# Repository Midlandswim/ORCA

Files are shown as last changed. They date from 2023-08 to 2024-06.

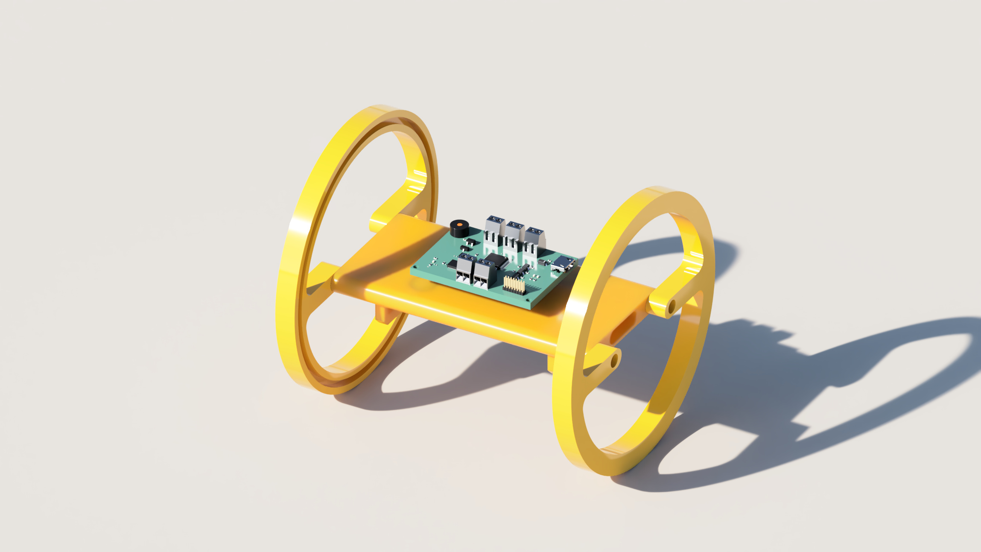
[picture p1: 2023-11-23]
Media/RandomProgressPics/ORCA_Electronics_Bay_2023-Nov-12_01.jpg

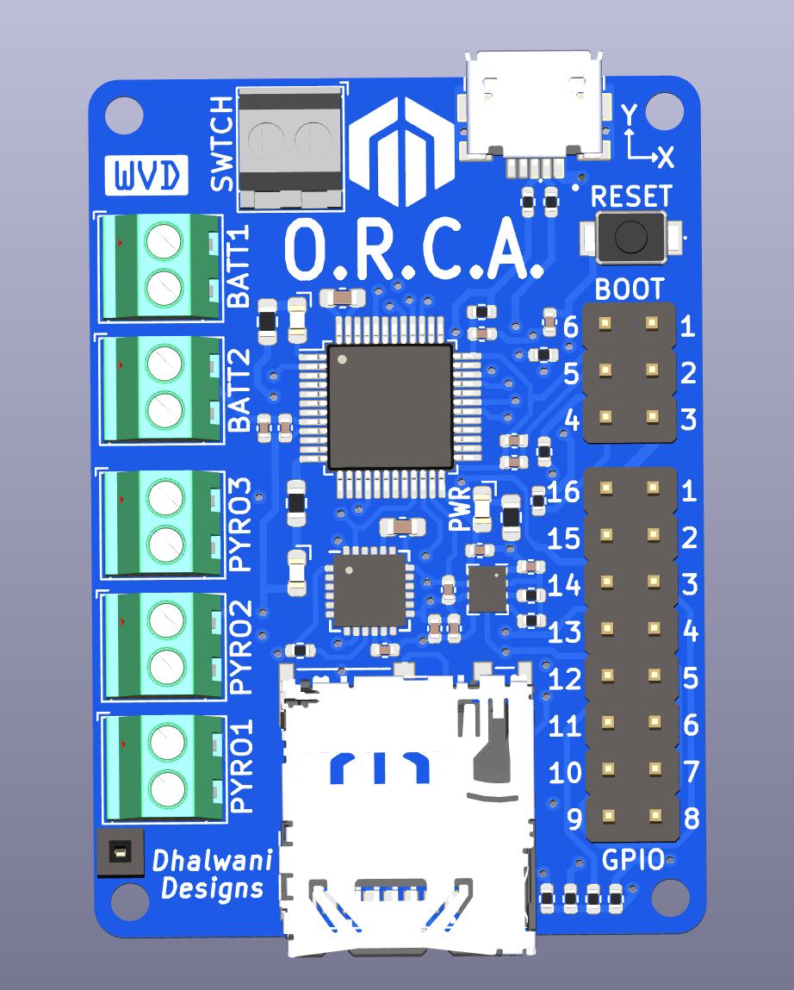
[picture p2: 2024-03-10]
Media/Version 4.0/Screenshot 2024-03-10 141300.png

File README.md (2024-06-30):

# O.R.C.A
Optimized Rocketry Computer Assembly

This is in partnership with Dhalwani Designs, which holds all rights, data, and procedures for this project and the related. <br />

Researcher: Wilson Dhalwani <br />
Aides: Mr. Michael Liva (BCA) & Mr. Joseph Barbetta (BCA) & Mr. Vladyslav Kharechko (BCA) <br />
Context: Dhalwani Designs Sanctioned Project, Senior Capstone, and Electrical Engineering Research Project <br />
Project Name: The Optimized Rocketry Computer Assembly <br />
Start Date: June 06, 2023 <br /> 

The following repository is for documenting and sharing my work in this research and capstone project and its related fields of electrical and avionics engineering. This was also made to record my process of solving the issue at hand so that others can learn and build upon my work. The O.R.C.A was inspired by work and research with various competitive rocketry teams, who came with concerns for traditional flight computers, which tended to be large, involved, and bulky, affecting performance and technical usage. This led to me going down a rabbit hole of avionics and the niche community that came with flight computer design. After spending hours in KiCAD, EAGLE, and JLCPCB Assembly Libraries, I found myself intrigued by the idea of an ultra-compact, one that was far smaller than the conventional flight computer and many times more capable. And, after many weeks of research and design, I came up with the first prototype for O.R.C.A, a board that was 60 mm by 72 mm, however, this was not good enough. Small was the name of the game, and with the discovery of 0402 SMD components, I managed to bring it down to less than 47 mm by 34 mm, small enough to fight in the palm of your hand! I would eventually bring this work over, as part of my Senior Engineering Capstone (yes, I am ahead of schedule), to hopefully share my work in avionics so that others could be inspired by what I did, and collaborate towards even smaller boards. The evolution of Printed Circuit Board design is at its peak, and the innovation in the electronics industry is mesmerizing, allowing for some cool creations and hopefully even more compact and powerful designs in the future. With that being said, optimized is used loosely, as I am sure in a month or so, we will have components even smaller than 0201 generally available, especially with the recent advances in Flex PCBs. I completely designed the entire system, top-down, using KiCAD, snapEDA for parts libraries, and JLCPCB for SMD component libraries. The amazing thing about this board, despite its size and power, is its capability and the ability to be applied to many scenarios and uses. With the great populace of onboard sensors, abundant and expandable memory, and the amazing MCU, this board can be programmed for rockets, drones, and more. Currently, time is being spent on updating and improving firmware, and work is currently being done on a new and improved version 4.0, so be on the lookout for that in the coming months! This project has no end date as an innovation never ends, rather, continues until the idea is forgotten, and my hope is that this work can be the basis for future engineers who, too, find great excitement in innovation and design. <br />

Should you have any questions, comments, or just wish to reach out, email me at wilson.dhalwani@gmail.com !

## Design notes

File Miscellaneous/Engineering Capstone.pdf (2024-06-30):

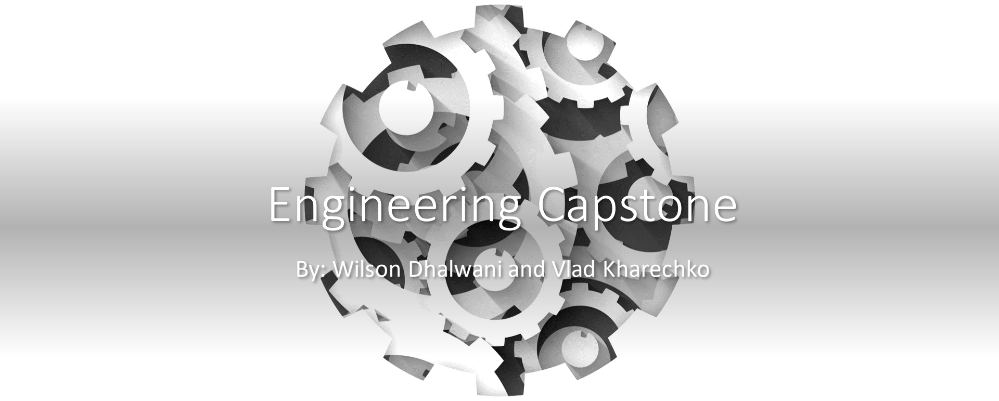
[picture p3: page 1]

# Engineering Capstone

## By: Wilson Dhalwani and Vlad Kharechko

# Idea

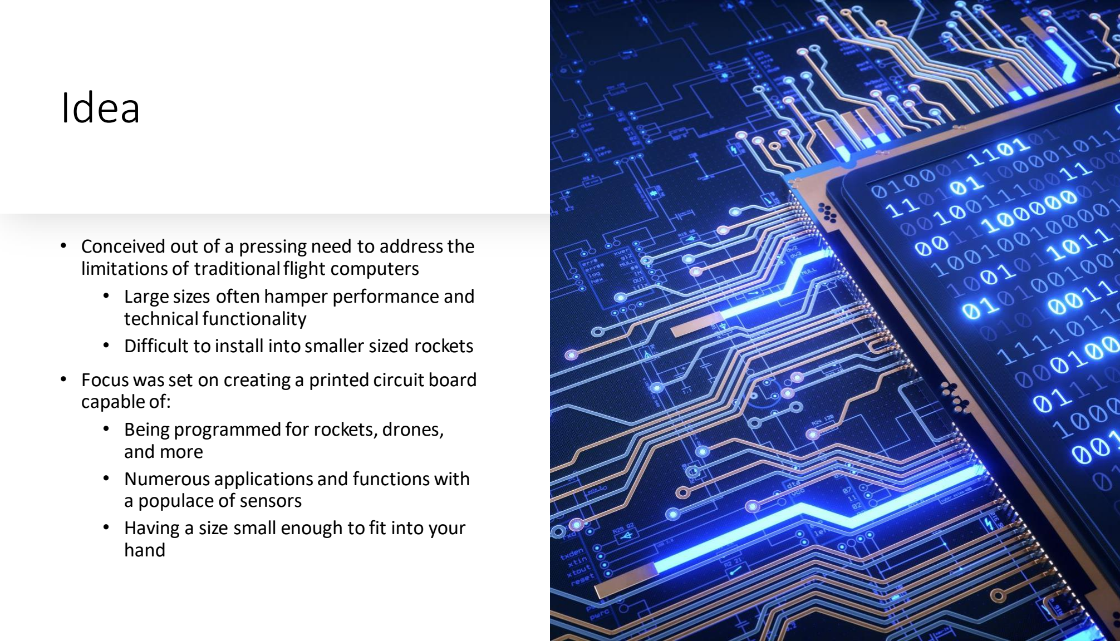
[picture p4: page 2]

- Conceived out of a pressing need to address the limitations of traditional flight computers
- Large sizes often hamper performance and technical functionality
- Difficult to install into smaller sized rockets
- Focus was set on creating a printed circuit board capable of:
- Being programmed for rockets, drones, and more
- Numerous applications and functions with a populace of sensors
- Having a size small enough to fit into your hand

# Solution - O.R.C.A

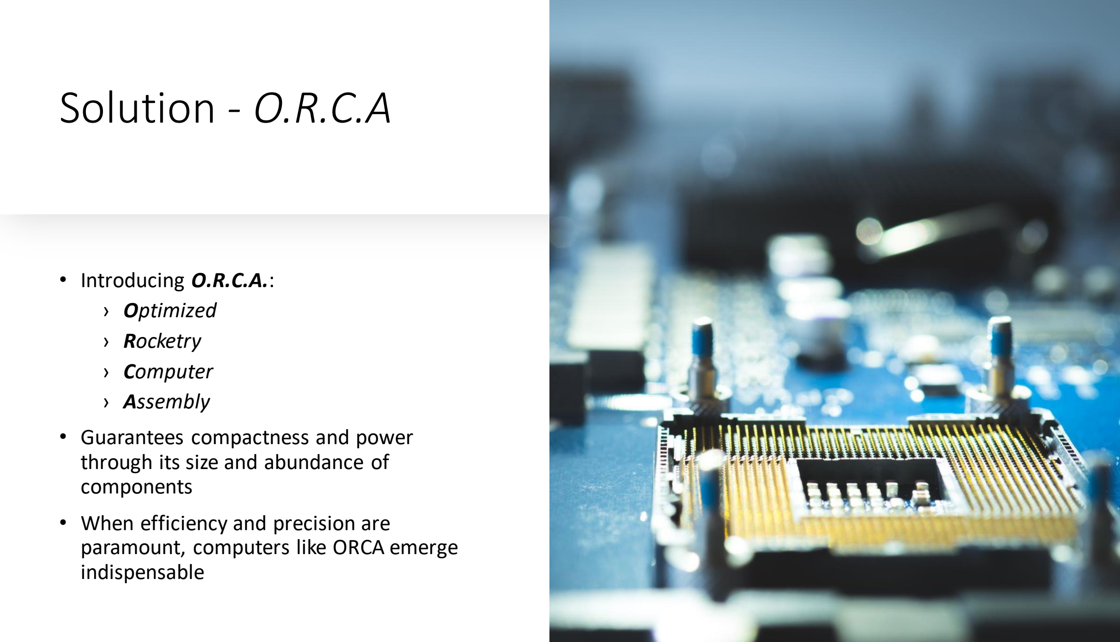
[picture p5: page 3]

### - Introducing O.R.C.A.: › Optimized › Rocketry › Computer › Assembly - Guarantees compactness and power through its size and abundance of components

### - When efficiency and precision are paramount, computers like ORCA emerge indispensable

# Bill of Materials

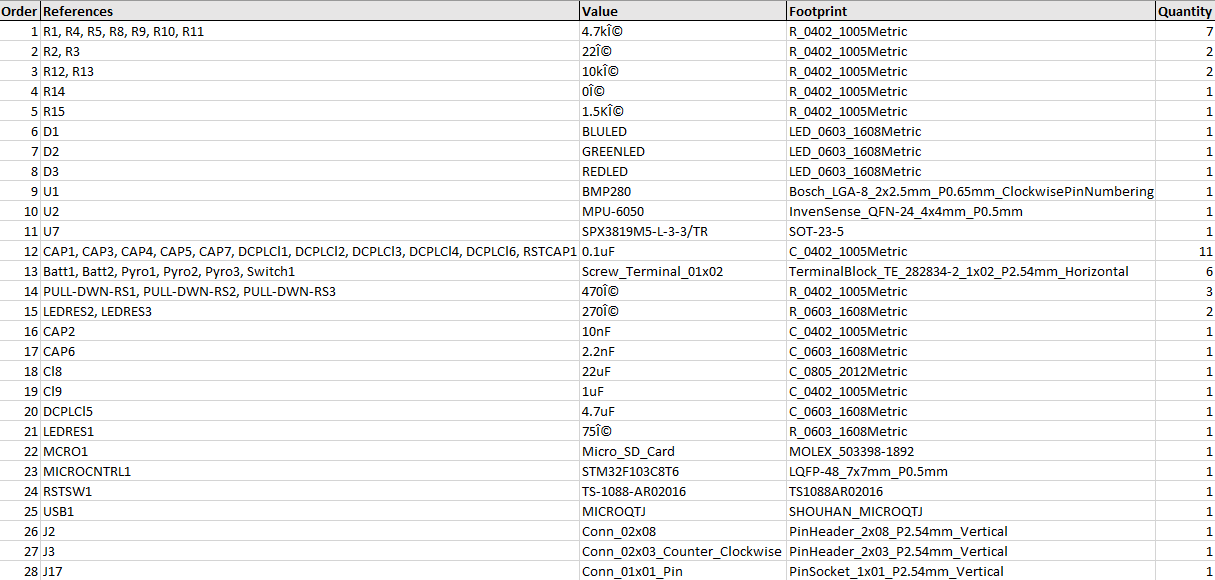
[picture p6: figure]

# Visuals

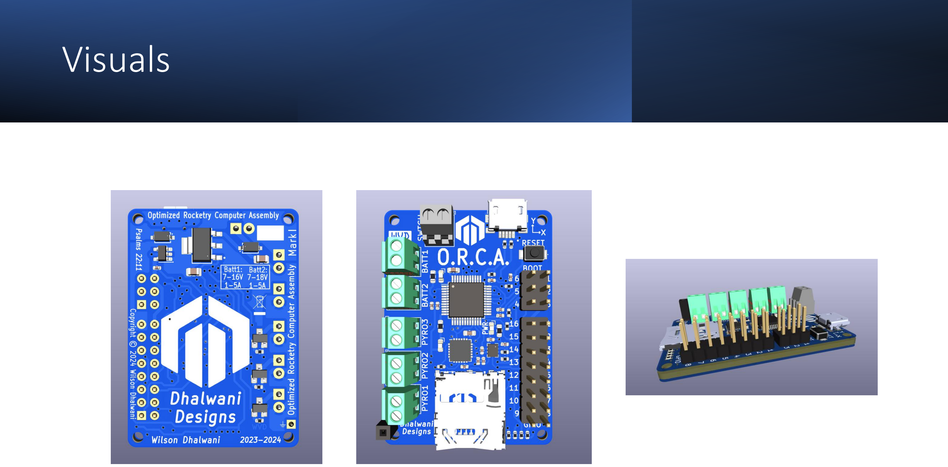
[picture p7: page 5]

# Tools Used

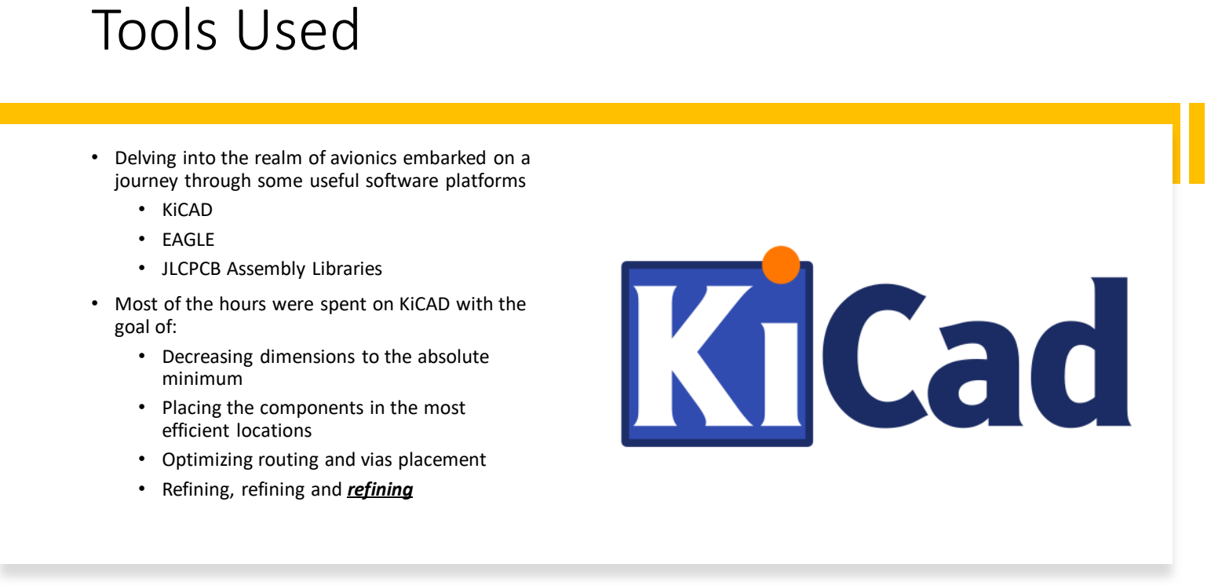
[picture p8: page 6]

- Delving into the realm of avionics embarked on a journey through some useful software platforms
- KiCAD
- EAGLE
- JLCPCB Assembly Libraries
- Most of the hours were spent on KiCAD with the goal of:
- Decreasing dimensions to the absolute minimum
- Placing the components in the most efficient locations
- Optimizing routing and vias placement
- Refining, refining and refining

# Sponsorship

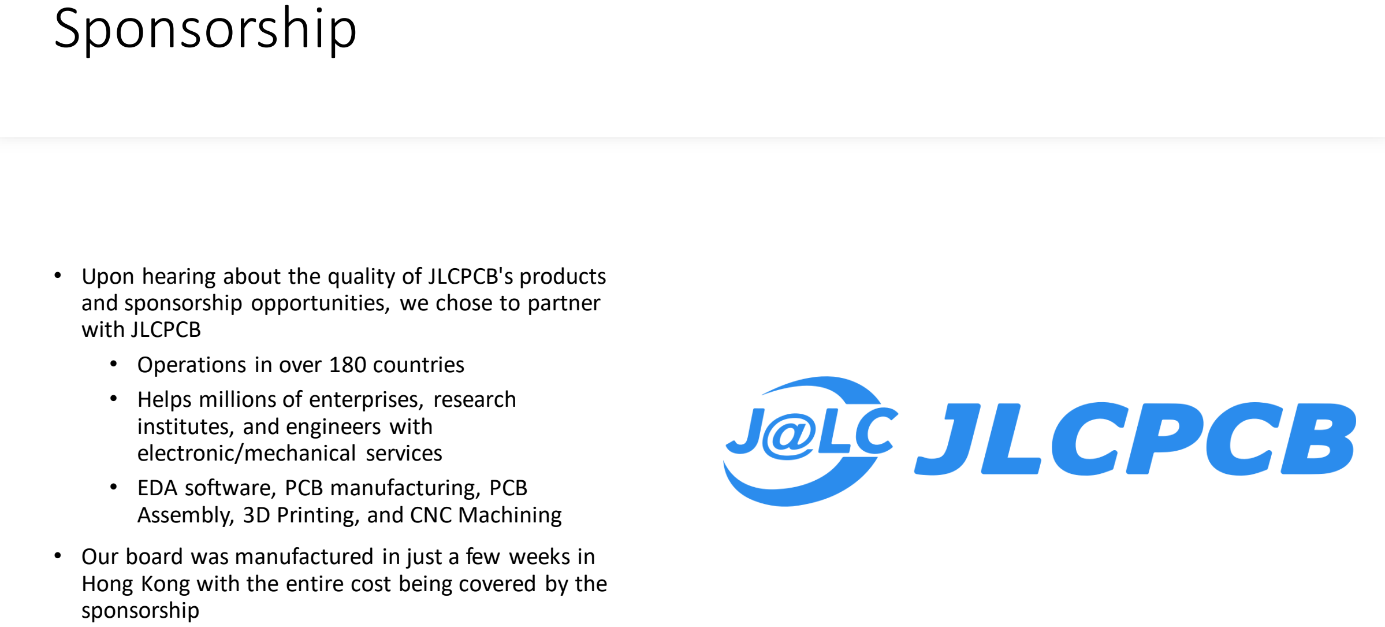
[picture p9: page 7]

- Upon hearing about the quality of JLCPCB's products and sponsorship opportunities, we chose to partner with JLCPCB
- Operations in over 180 countries
- Helps millions of enterprises, research institutes, and engineers with electronic/mechanical services
- EDA software, PCB manufacturing, PCB Assembly, 3D Printing, and CNC Machining
- Our board was manufactured in just a few weeks in Hong Kong with the entire cost being covered by the sponsorship

# Physical board

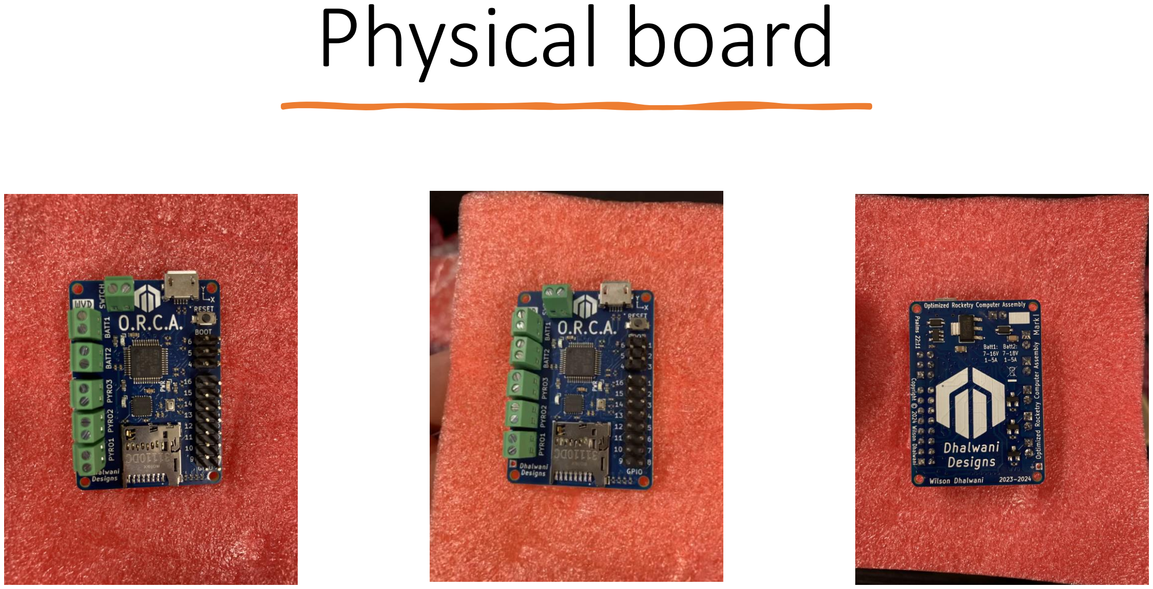
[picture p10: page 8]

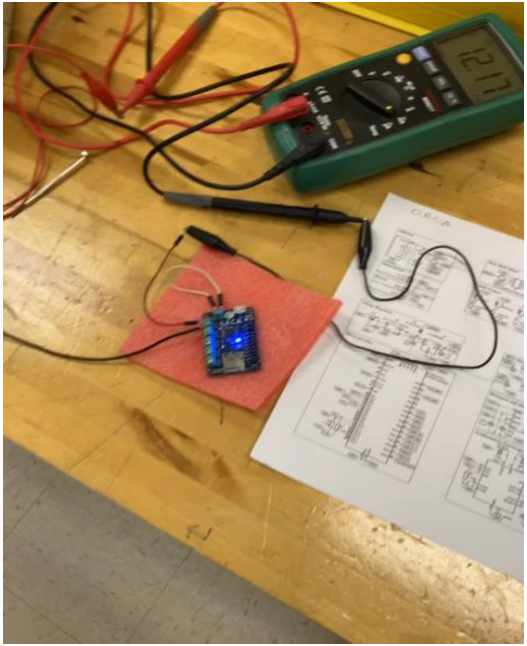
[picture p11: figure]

# Testing

# HUUUUUUUUUUUUUUGE THANKS to Mr. Barbetta and Mr. Liva for helping us

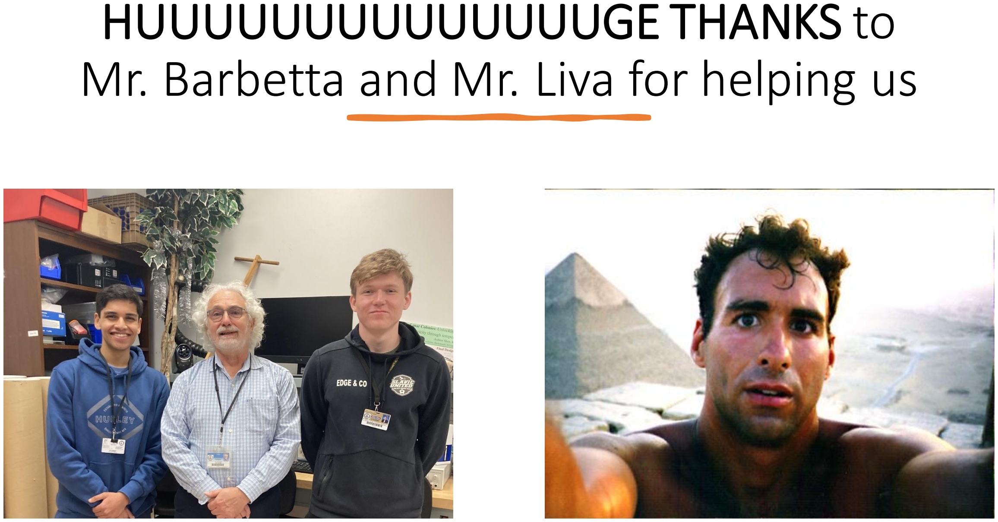
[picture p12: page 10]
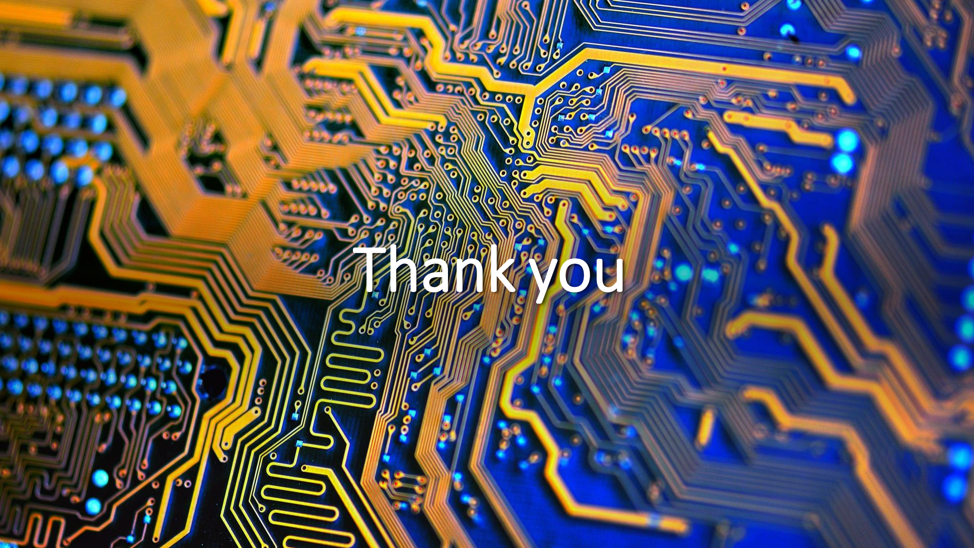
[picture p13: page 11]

# Thank you

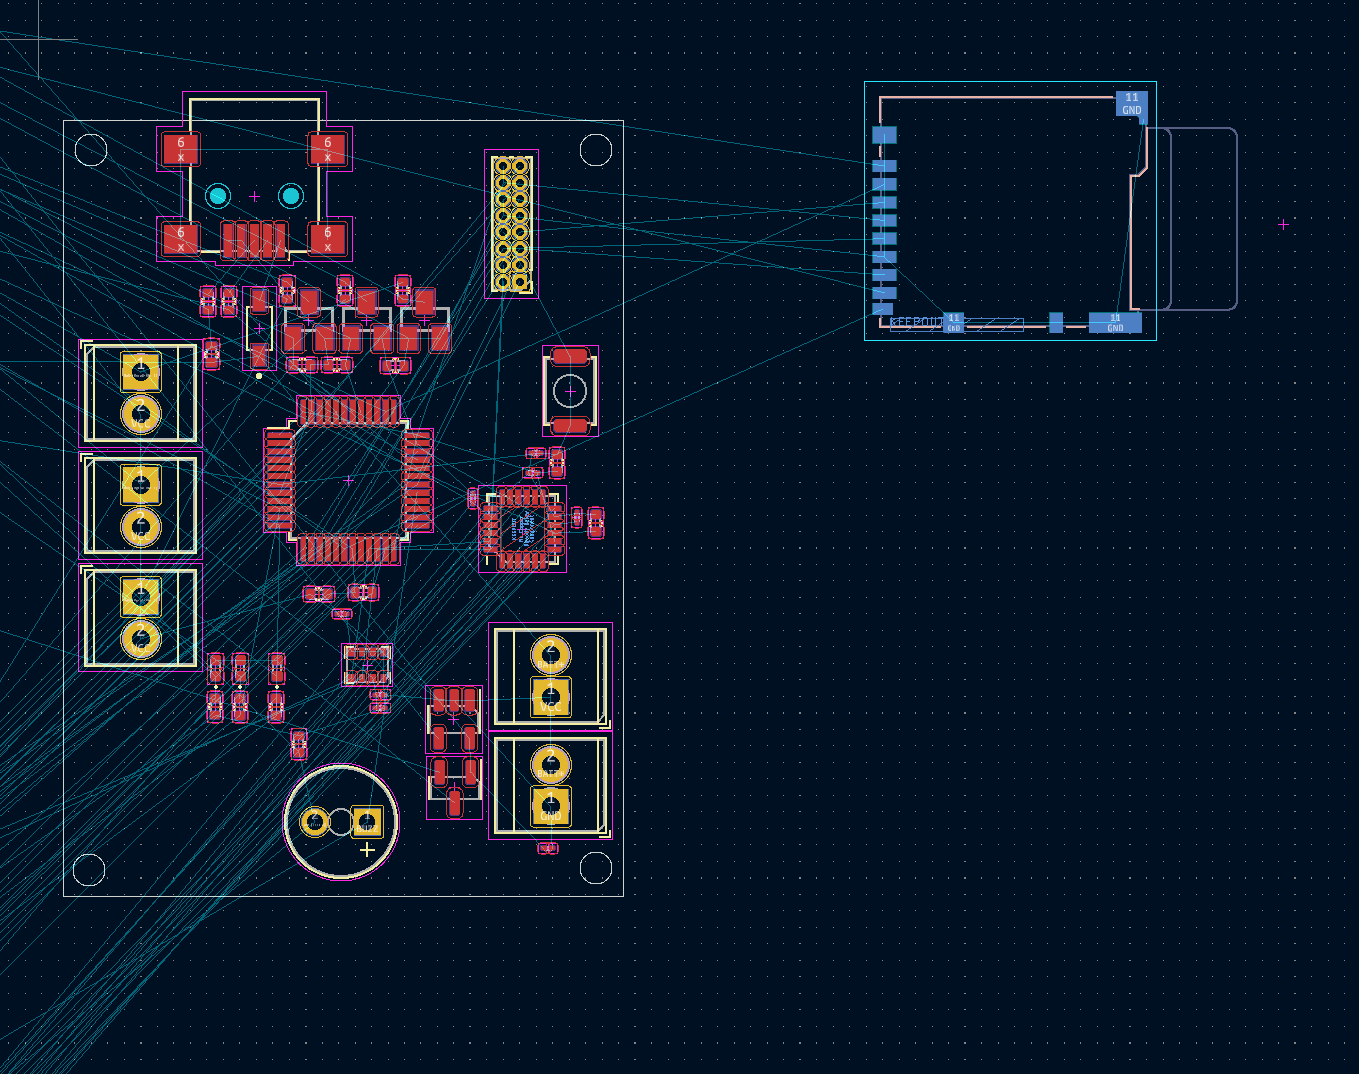
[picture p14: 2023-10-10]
Media/RandomProgressPics/DoubleSidedPCBAttempt1.png

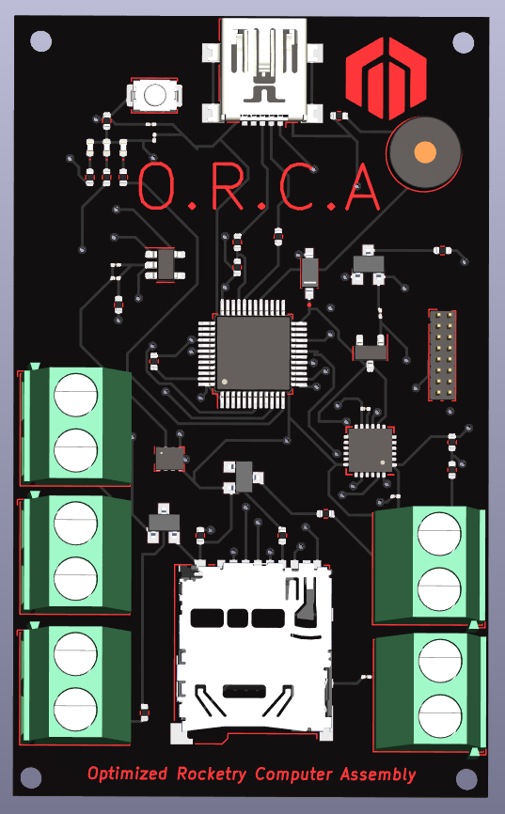
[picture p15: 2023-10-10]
Media/RandomProgressPics/BoardRenderFront.png

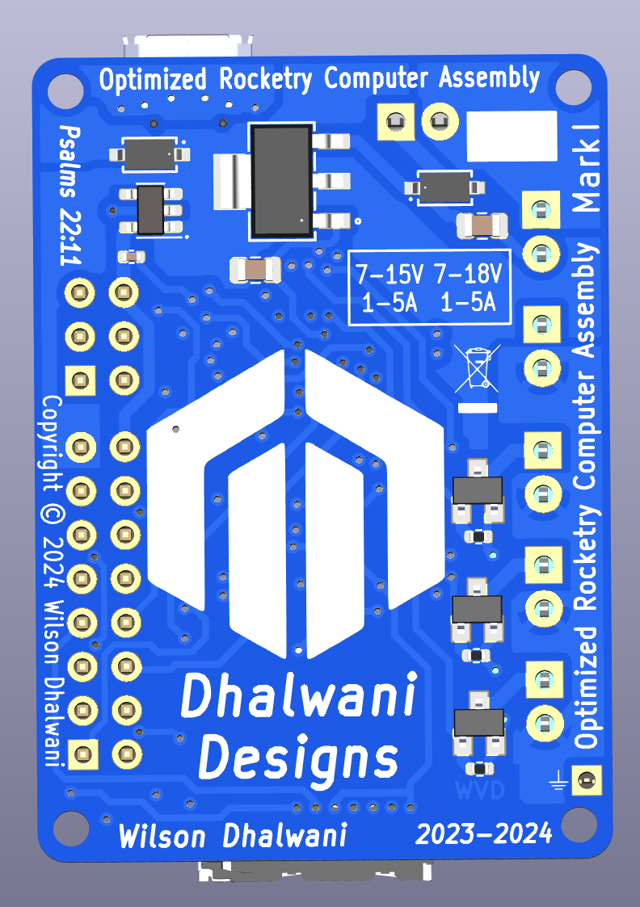
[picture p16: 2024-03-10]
Media/Version 4.0/Screenshot 2024-03-10 141330.png

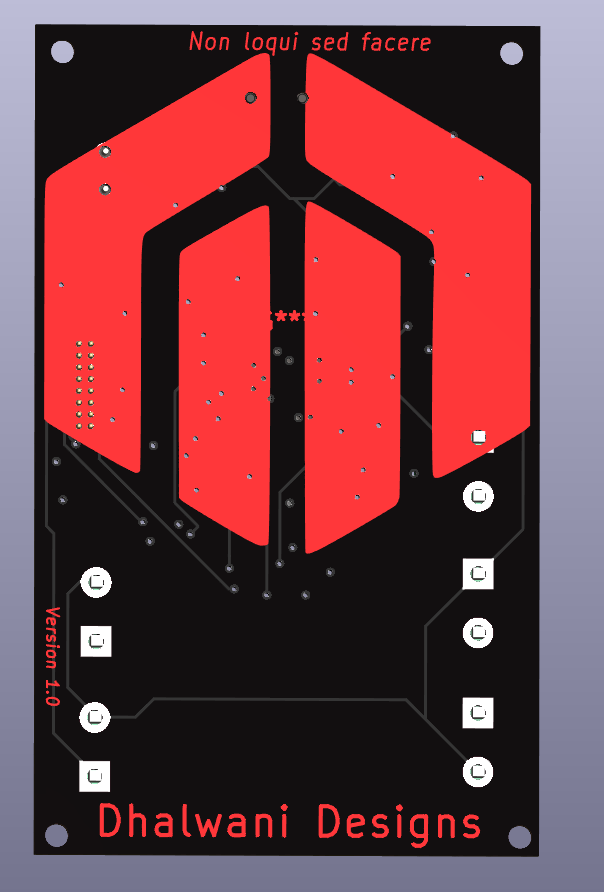
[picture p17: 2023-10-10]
Media/RandomProgressPics/BoardRenderBack.png

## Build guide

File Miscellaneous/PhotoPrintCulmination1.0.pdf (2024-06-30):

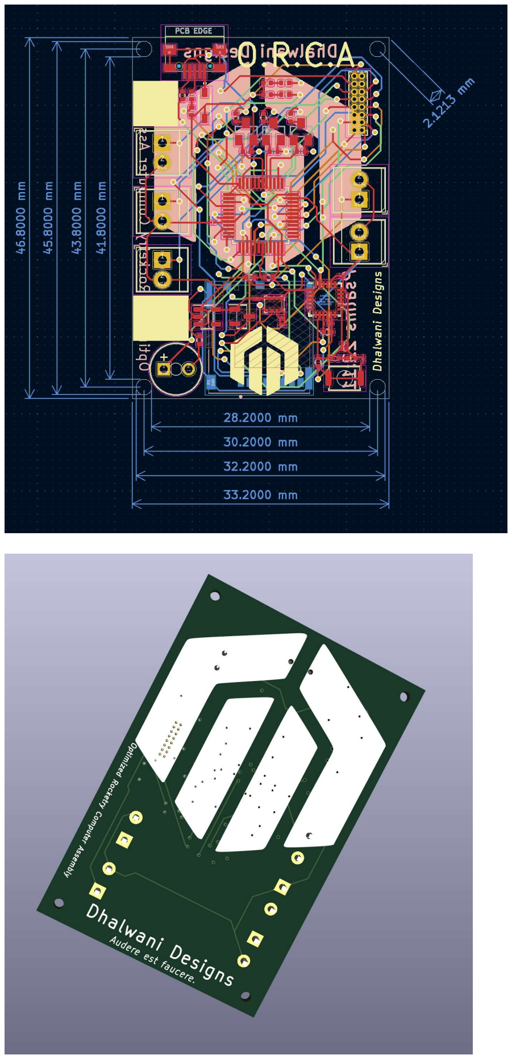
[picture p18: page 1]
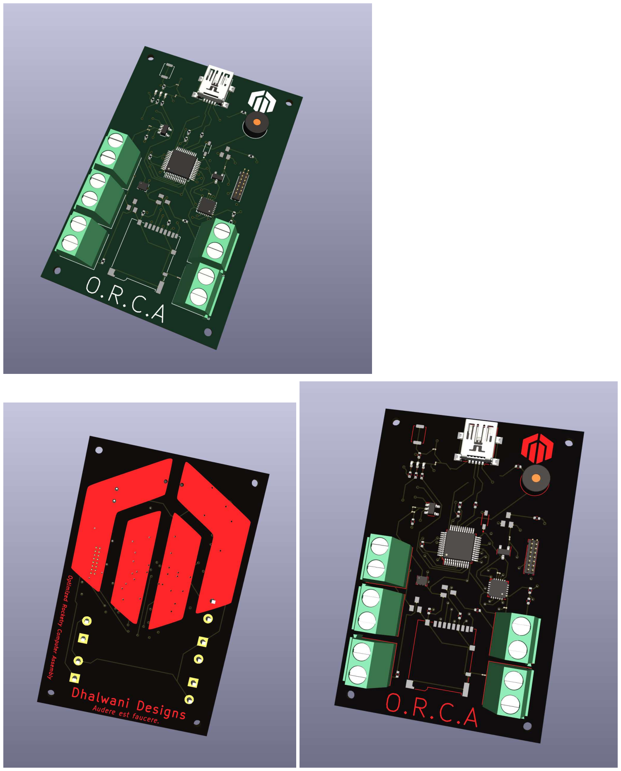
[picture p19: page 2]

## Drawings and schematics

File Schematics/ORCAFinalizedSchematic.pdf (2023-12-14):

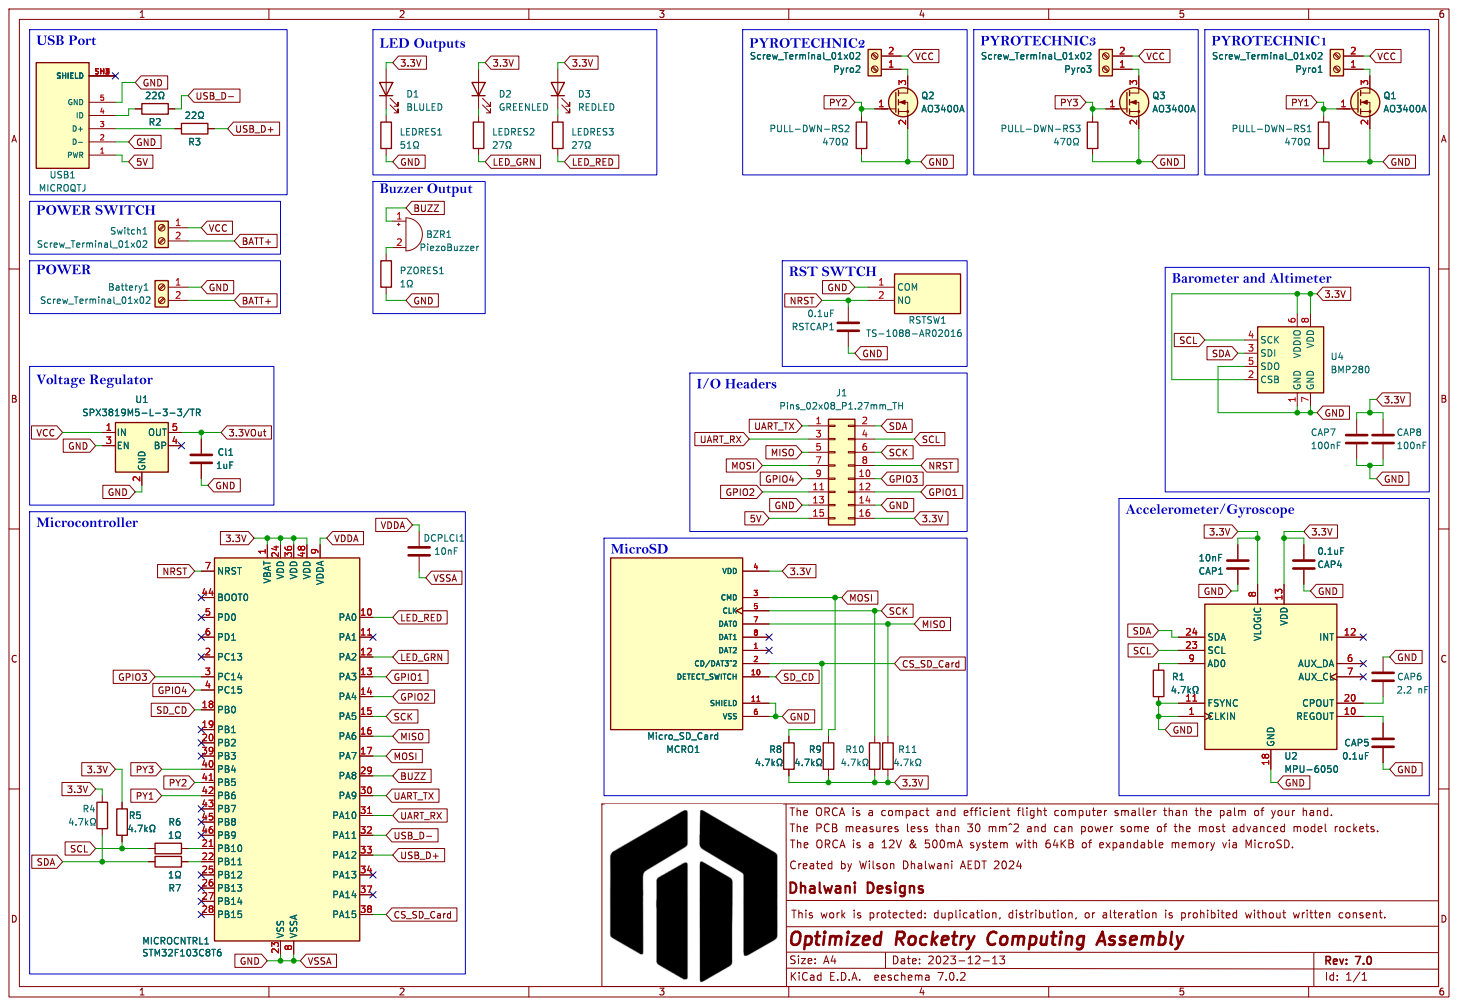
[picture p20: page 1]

1 CSB 2 SDI 3 SCK 4 SDO 5 VDDIO

2 EN 3 BP 4 OUT 5 U1 SPX3819M5-L-3-3/TR

1 PA0 10 PA1 11 PA2 12 PA3 13 PA4 14 PA5 15 PA6 16 PA7 17 PB0 18 PB1 19 PC13 2 PB2 20 PB10 21 PB11 22 VSS 23 VDD 24 PB12 25 PB13 26 PB14 27 PB15 28 PA8 29 PC14 3 PA9 30 PA10 31 PA11 32 PA12 33 PA13 34 VDD 36 PA14 37 PA15 38 PB3 39 PC15 4 PB4 40 PB5 41 PB6 42 PB7 43 BOOT0 44 PB8 45 PB9 46 VDD 48 PD0 5 PD1 6 NRST 7 VSSA

Id: 1/1 Optimized Rocketry Computing Assembly

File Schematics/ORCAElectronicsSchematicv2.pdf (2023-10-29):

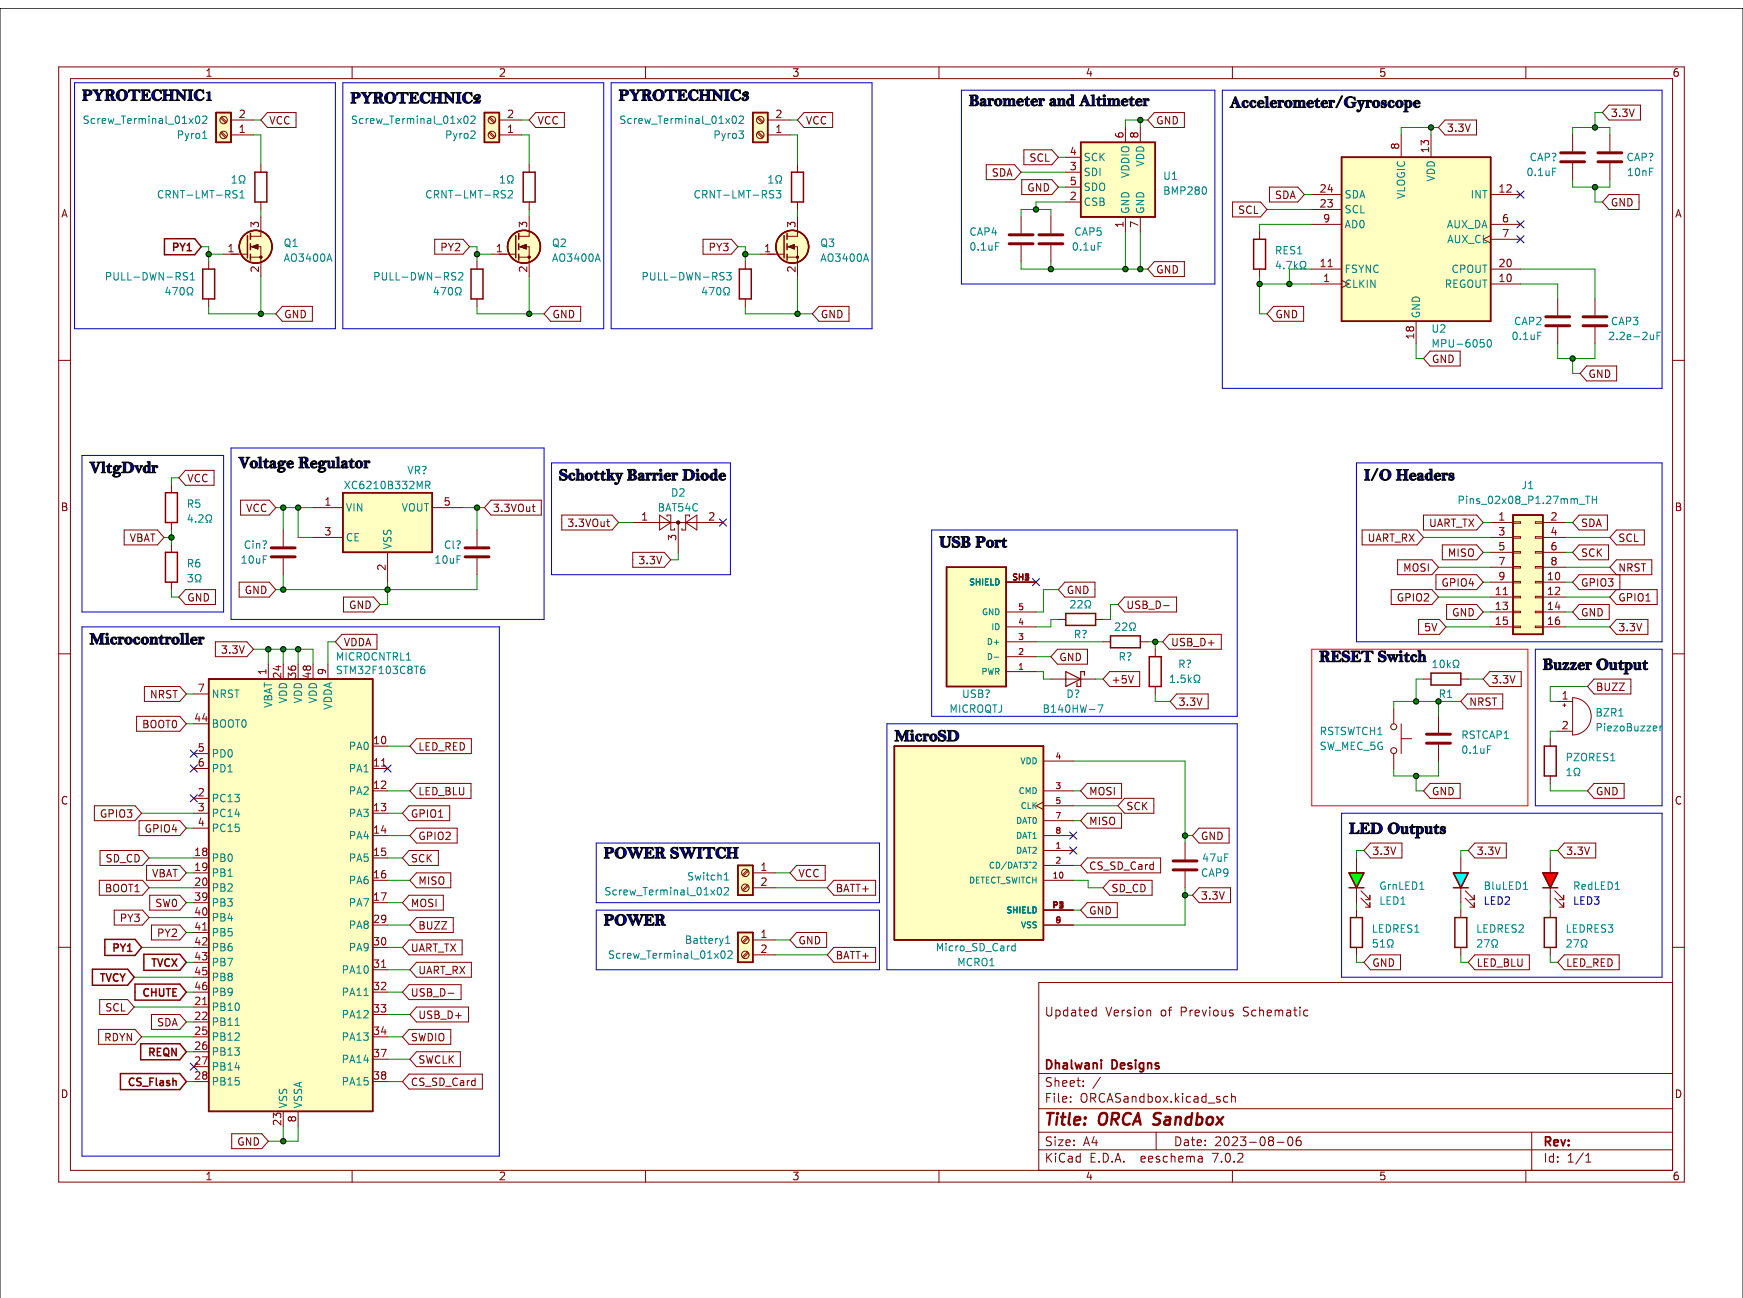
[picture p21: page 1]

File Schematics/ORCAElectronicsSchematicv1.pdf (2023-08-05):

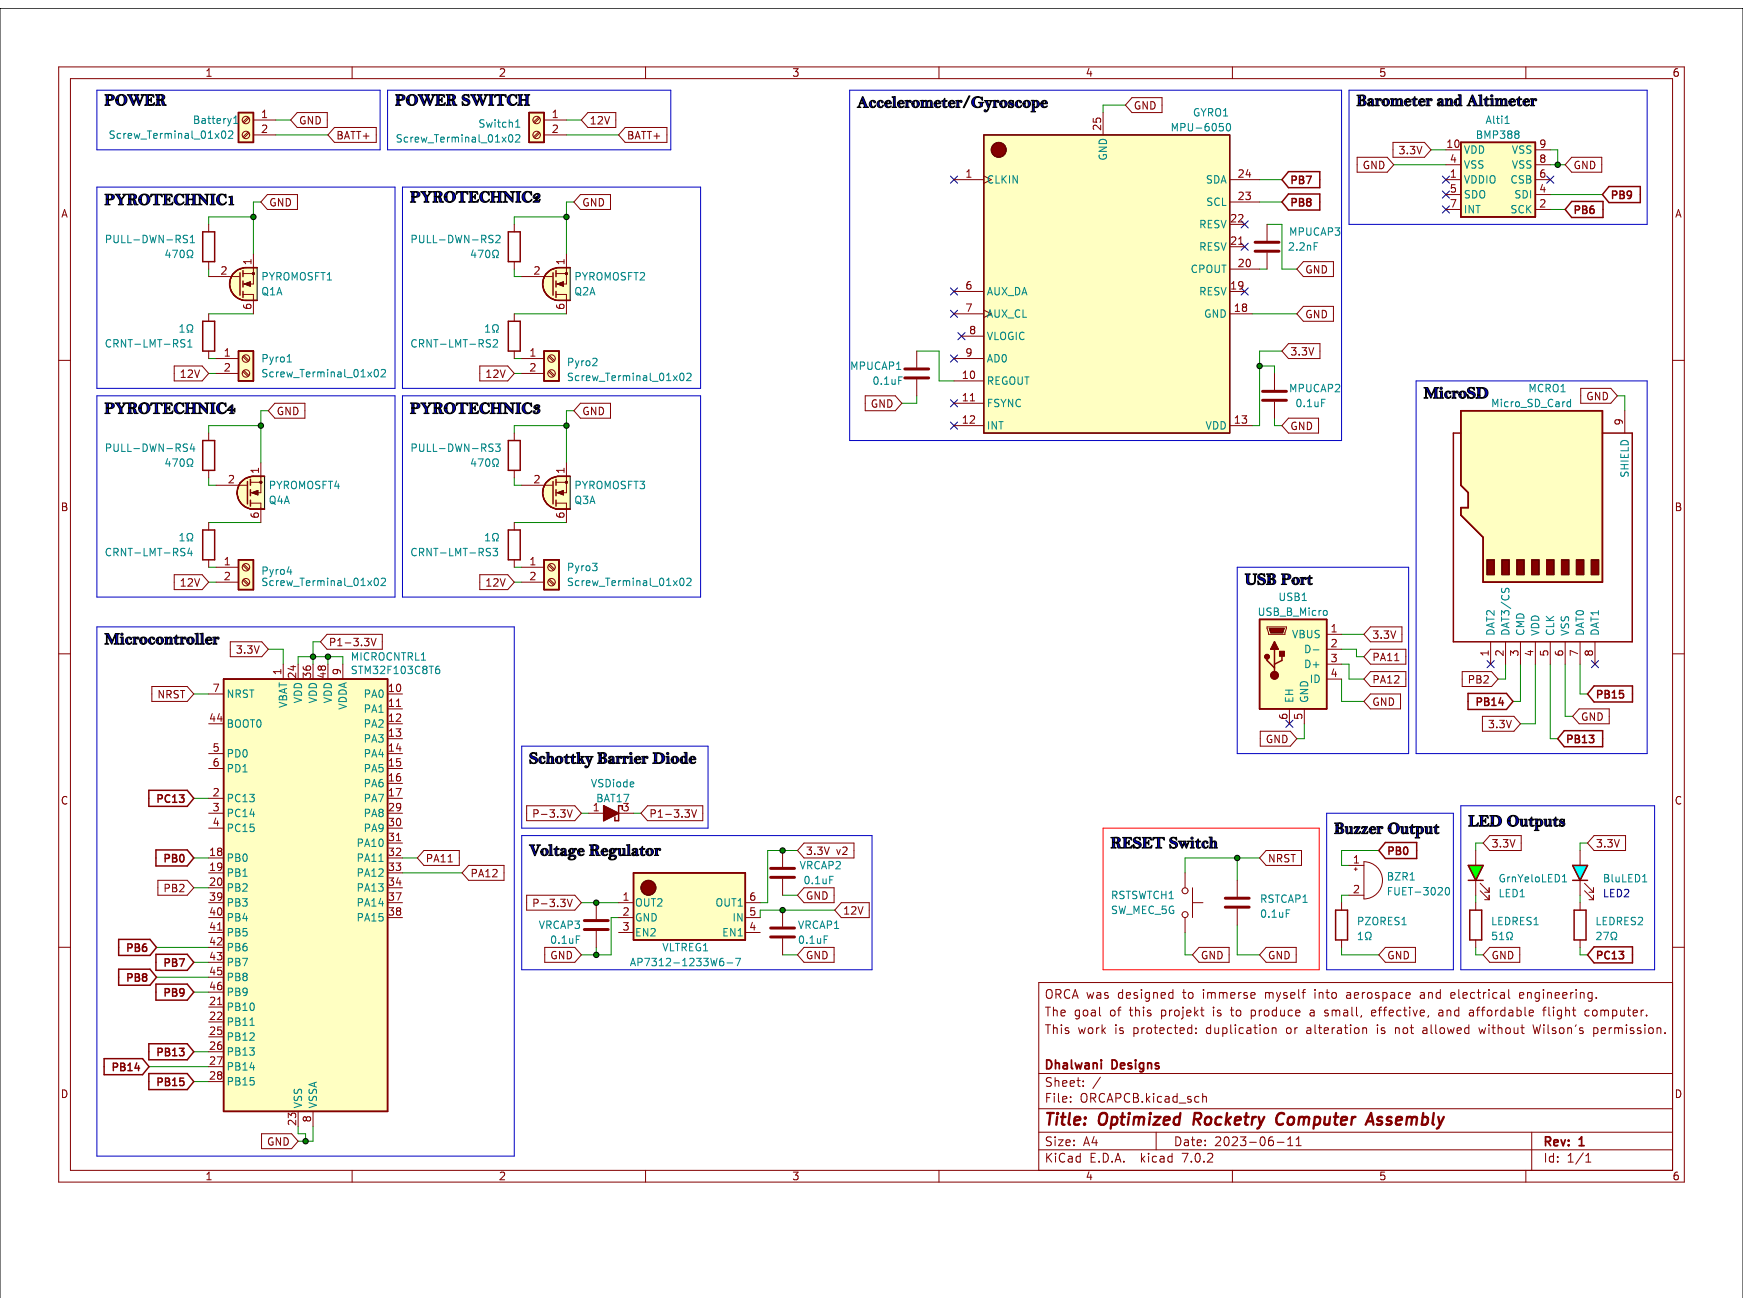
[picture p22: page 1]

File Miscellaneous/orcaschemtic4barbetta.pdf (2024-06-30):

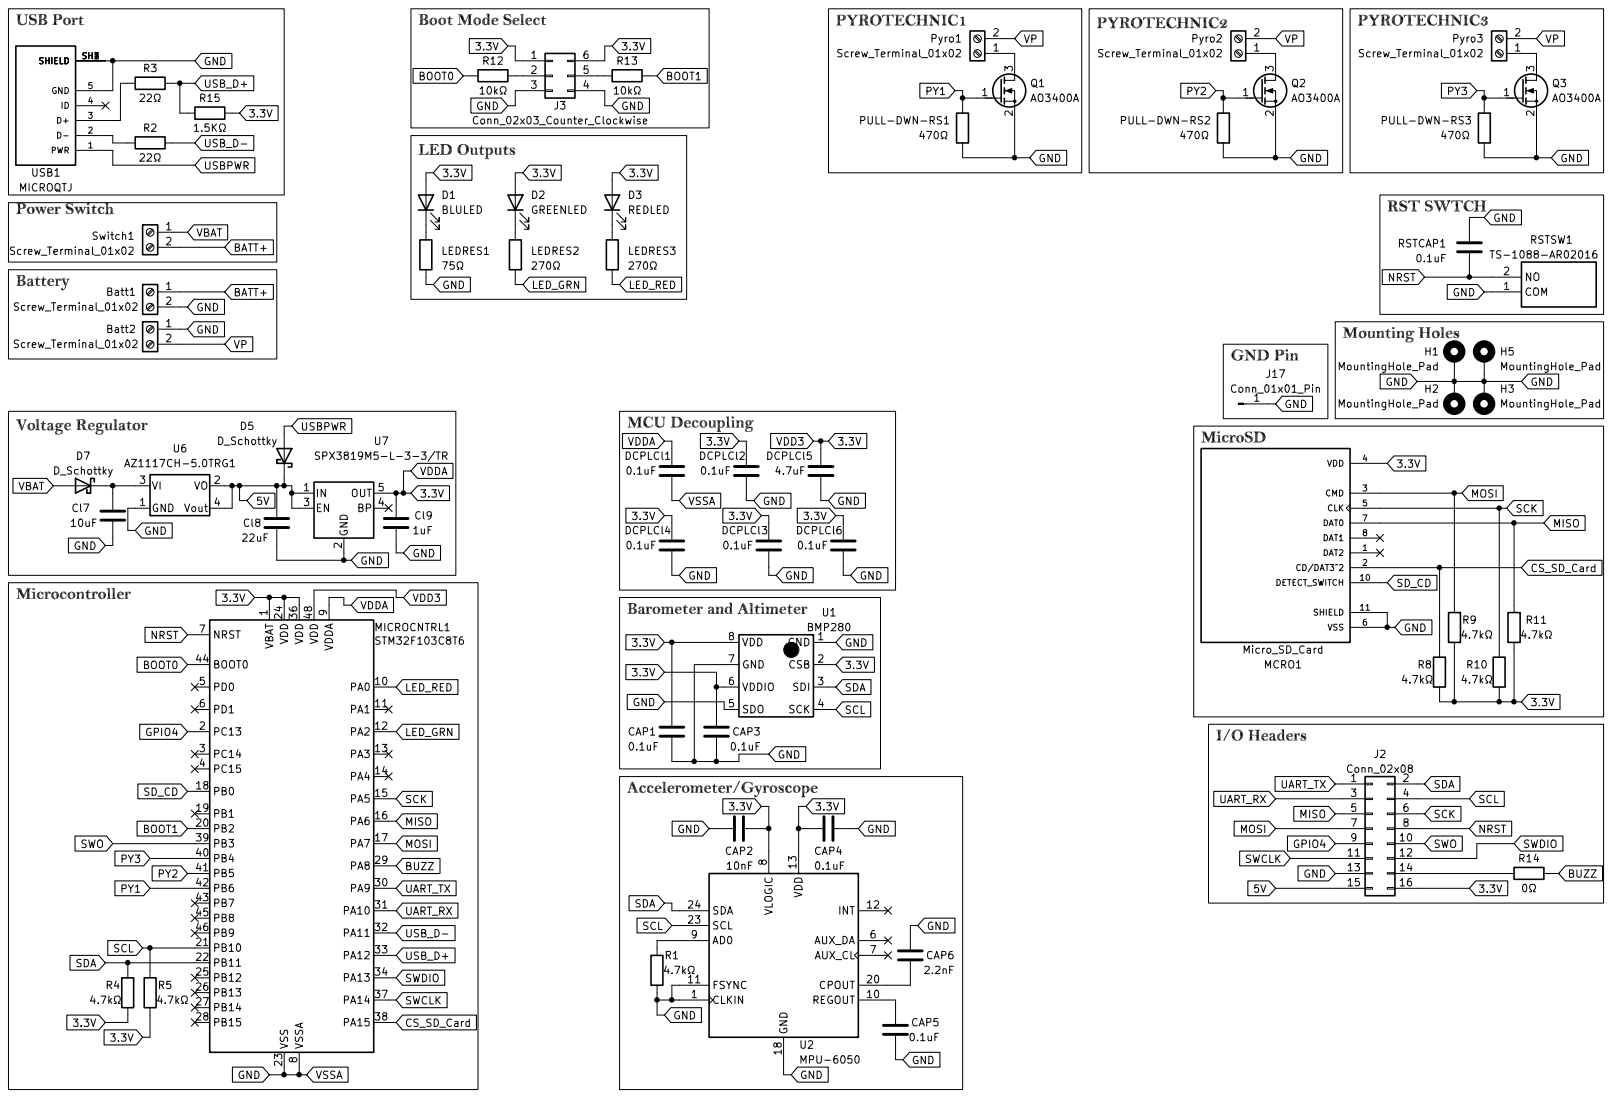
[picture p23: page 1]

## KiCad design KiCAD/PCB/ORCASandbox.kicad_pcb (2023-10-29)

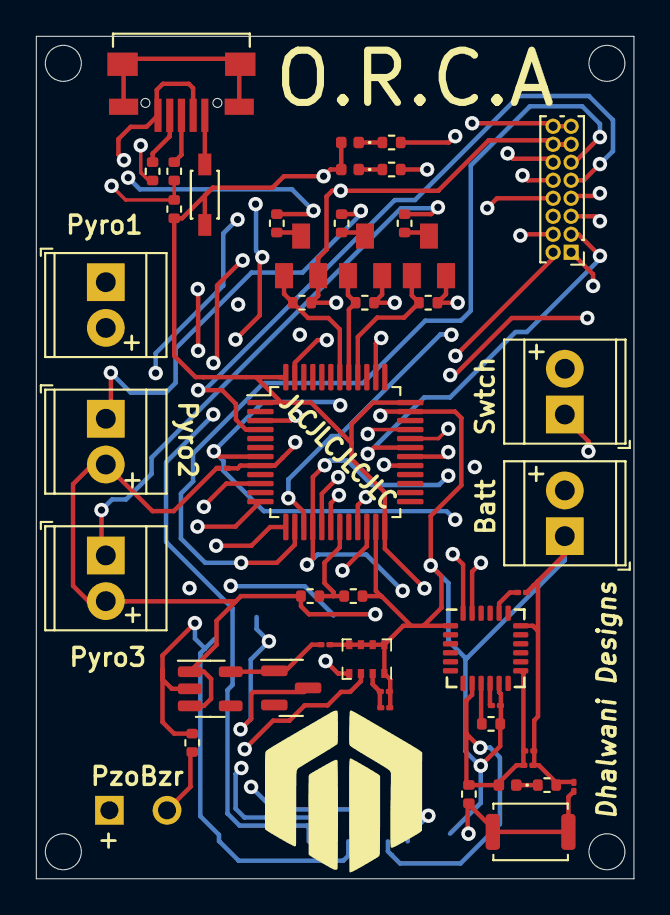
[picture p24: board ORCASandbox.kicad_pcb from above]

Board: 4 copper layers, 33.2 x 46.8 mm, 48 parts (1 on the bottom side), 45 nets.

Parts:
BZR1: PiezoBuzzer; MagneticBuzzer_Kingstate_KCG0601
Battery1: Screw_Terminal_01x02; TerminalBlock_TE_282834-2_1x02_P2.54mm_Horizontal
BluLED1: LED2; LED_0402_1005Metric
CAP1, CAP9: 47uF; C_01005_0402Metric
CAP2, CAP4, CAP5: 0.1uF; C_01005_0402Metric
CAP3: 2.2e-2uF; C_01005_0402Metric
CAP6, CAP7: 10uF; C_01005_0402Metric
CRNT-LMT-RS1, CRNT-LMT-RS2, CRNT-LMT-RS3: 1Ω; R_0402_1005Metric
D1: B140HW-7; SOD3715X135N
D2: BAT54C; SOT-23
GrnLED1: LED1; LED_0402_1005Metric
J1: Pins_02x08_P1.27mm_TH; PinHeader_2x08_P1.00mm_Vertical
LEDRES1: 51Ω; R_0402_1005Metric
LEDRES2, LEDRES3: 27Ω; R_0402_1005Metric
MCRO1: Micro_SD_Card; MOLEX_503398-1892
MICROCNTRL1: STM32F103C8T6; LQFP-48_7x7mm_P0.5mm
PULL-DWN-RS1, PULL-DWN-RS2, PULL-DWN-RS3: 470Ω; R_0402_1005Metric
PZORES1: 1Ω; R_0402_1005Metric
Pyro1, Pyro2, Pyro3: Screw_Terminal_01x02; TerminalBlock_TE_282834-2_1x02_P2.54mm_Horizontal
Q1, Q2, Q3: AO3400A; SOT23
R1: 10kΩ; R_0402_1005Metric
R2, R3: 22Ω; R_0402_1005Metric
R4: 1.5kΩ; R_0402_1005Metric
R5: 4.2Ω; R_0402_1005Metric
R6: 3Ω; R_0402_1005Metric
RES1: 4.7kΩ; R_0402_1005Metric
RSTCAP1: 0.1uF; C_01005_0402Metric
RSTSWTCH1: SW_MEC_5G; SW_Push_SPST_NO_Alps_SKRK
RedLED1: LED3; LED_0402_1005Metric
Switch1: Screw_Terminal_01x02; TerminalBlock_TE_282834-2_1x02_P2.54mm_Horizontal
U1: BMP280; Bosch_LGA-8_2x2.5mm_P0.65mm_ClockwisePinNumbering
U2: MPU-6050; InvenSense_QFN-24_4x4mm_P0.5mm
U3: XC6210B332MR; SOT-23-5
USB1: MICROQTJ; SHOUHAN_MICROQTJ

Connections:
3.3V: BluLED1.2 (A), CAP1.2, CAP9.2, D1.A, D2.3, GrnLED1.2 (A), J1.15, J1.16, MCRO1.6 (VSS), MCRO1.9 (VSS), MICROCNTRL1.1 (VBAT), MICROCNTRL1.24 (VDD), MICROCNTRL1.36 (VDD), MICROCNTRL1.48 (VDD), R1.1, R4.2, RedLED1.2 (A), U2.8 (VLOGIC), U2.13 (VDD)
3.3VOut: CAP7.1, D2.1, U3.5 (VOUT)
BATT+: Battery1.2, Switch1.2
BUZZ: BZR1.1 (-), MICROCNTRL1.29 (PA8)
CS_SD_Card: MCRO1.2 (CD/DAT3^2), MICROCNTRL1.38 (PA15)
GND: Battery1.1, CAP1.1, CAP2.2, CAP3.2, CAP4.2, CAP5.2, CAP6.2, CAP7.2, CAP9.1, J1.13, J1.14, LEDRES1.2, MCRO1.4 (VDD), MCRO1.P1 (SHIELD), MCRO1.P2 (SHIELD), MCRO1.P3 (SHIELD), MCRO1.P4 (SHIELD), MICROCNTRL1.8 (VSSA), MICROCNTRL1.23 (VSS), MICROCNTRL1.35 (VSS), MICROCNTRL1.47 (VSS), PULL-DWN-RS1.2, PULL-DWN-RS2.2, PULL-DWN-RS3.2, PZORES1.2, Q1.2 (S), Q2.2 (S), Q3.2 (S), R6.2, RES1.2, RSTCAP1.2, U1.1 (GND), U1.5 (SDO), U1.6 (VDDIO), U1.7 (GND), U1.8 (VDD), U2.1 (CLKIN), U2.11 (FSYNC), U2.18 (GND), U3.2 (GND), USB1.2 (D-), USB1.5 (GND)
GPIO1: J1.12, MICROCNTRL1.13 (PA3)
GPIO2: J1.11, MICROCNTRL1.14 (PA4)
GPIO3: J1.10, MICROCNTRL1.3 (PC14)
GPIO4: J1.9, MICROCNTRL1.4 (PC15)
LED_BLU: LEDRES2.2, MICROCNTRL1.12 (PA2)
LED_RED: LEDRES3.2, MICROCNTRL1.10 (PA0)
MISO: J1.5, MCRO1.7 (DAT0), MICROCNTRL1.16 (PA6)
MOSI: J1.7, MCRO1.3 (CMD), MICROCNTRL1.17 (PA7)
NRST: J1.8, MICROCNTRL1.7 (NRST), R1.2, RSTCAP1.1, RSTSWTCH1.1 (A), RSTSWTCH1.2 (A)
unnamed: BZR1.2 (+), PZORES1.1
unnamed: BluLED1.1 (K), LEDRES2.1
unnamed: D1.PWR, USB1.1 (PWR)
unnamed: GrnLED1.1 (K), LEDRES1.1
unnamed: CRNT-LMT-RS1.2, Pyro1.1
unnamed: CRNT-LMT-RS2.2, Pyro2.1
unnamed: CRNT-LMT-RS3.2, Pyro3.1
unnamed: CRNT-LMT-RS1.1, Q1.3 (D)
unnamed: CRNT-LMT-RS2.1, Q2.3 (D)
unnamed: CRNT-LMT-RS3.1, Q3.3 (D)
unnamed: LEDRES3.1, RedLED1.1 (K)
unnamed: CAP4.1, CAP5.1, U1.2 (CSB)
unnamed: RES1.1, U2.9 (AD0)
unnamed: CAP3.1, U2.20 (CPOUT)
unnamed: CAP2.1, U2.10 (REGOUT)
unnamed: R3.1, USB1.3 (D+)
unnamed: R2.1, USB1.4 (ID)
PY1: MICROCNTRL1.42 (PB6), PULL-DWN-RS1.1, Q1.1 (G)
PY2: MICROCNTRL1.41 (PB5), PULL-DWN-RS2.1, Q2.1 (G)
PY3: MICROCNTRL1.40 (PB4), PULL-DWN-RS3.1, Q3.1 (G)
SCK: J1.6, MCRO1.5 (CLK), MICROCNTRL1.15 (PA5)
SCL: J1.4, MICROCNTRL1.21 (PB10), U1.4 (SCK), U2.23 (SCL)
SDA: J1.2, MICROCNTRL1.22 (PB11), U1.3 (SDI), U2.24 (SDA)
SD_CD: MCRO1.10 (DETECT_SWITCH), MICROCNTRL1.18 (PB0)
UART_RX: J1.3, MICROCNTRL1.31 (PA10)
UART_TX: J1.1, MICROCNTRL1.30 (PA9)
USB_D+: MICROCNTRL1.33 (PA12), R3.2, R4.1
USB_D-: MICROCNTRL1.32 (PA11), R2.2
VBAT: MICROCNTRL1.19 (PB1), R5.2, R6.1
VCC: CAP6.1, Pyro1.2, Pyro2.2, Pyro3.2, R5.1, Switch1.1, U3.1 (VIN), U3.3 (CE)
